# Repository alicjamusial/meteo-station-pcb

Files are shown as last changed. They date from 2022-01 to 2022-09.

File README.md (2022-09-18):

# METEO STATION – PCB based on ESP32 


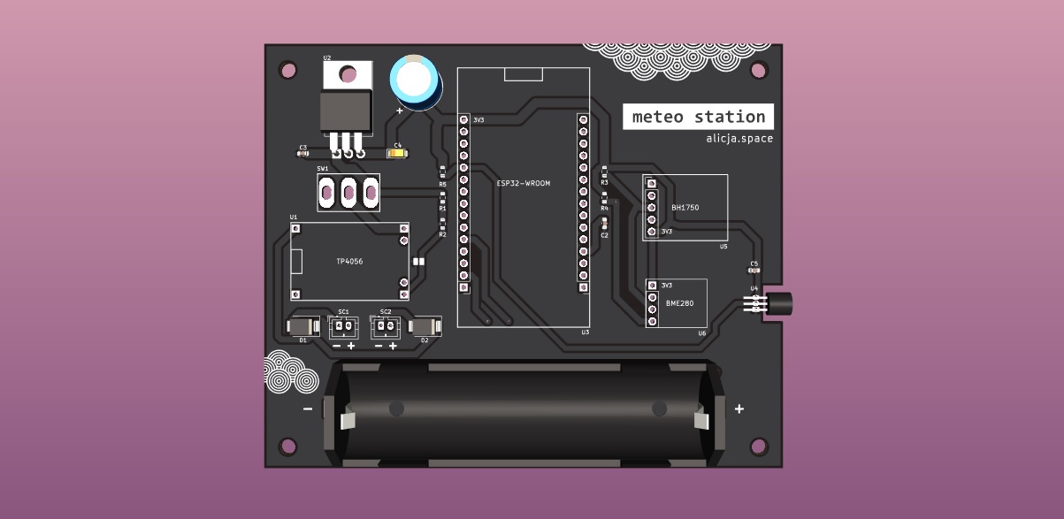
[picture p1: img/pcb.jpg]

<p align="center">
  Light
&nbsp; &nbsp; &nbsp;
  Dark
</p>

### ◾ About the project

**Meteo station** is my small after-hours project that contains of **three** repositories:
- Meteo station PCB based on ESP32 (this repo)
- [Meteo station code](https://github.com/alicjamusial/meteo-station-code)
- [Meteo station 3D prints](https://github.com/alicjamusial/meteo-station-3d-print)

As the name suggest, is a DIY self-sufficient weather measuring device. I decided to design it as a PCB board with goldpins to stick-in or stick-out individual components and sensors (ESP32, BME280 etc.) to make it more reusable. It could have - of course - been integrated on board, but it would be more expensive and time-consuming to create.

As you can see - the project is designed with minimal effort 🙂 But works!

> **Warning** <br>
> This is a hobbyist project. I'm not an electronic engineer so I take no responsibility for any possible issues you may encounter :)

Gerber files for version 1.0 of Meteo Station is available [in the releases section](https://github.com/alicjamusial/meteo-station/releases/tag/release-1.0.0).

The board was designed using [KiCad](https://kicad.org/) (version: `6.0`).

I was inspired by solution created by [this guy on Instructables](https://www.instructables.com/Solar-Powered-WiFi-Weather-Station-V30/). He did a good job, so I strongly recommand exploring his meteo projects!

### ◾ Sensors & components
**Components:**
- ESP32 (ESP-WROOM-32) - main computer (with LEDs, LDO, USB-to-UART unsoldered)
- TP4056 - battery charger
- solar panel - I finally used DFRobot FIT0601 Monocrystalline Solar Panel (5V, 1A)
- 18650 battery + holder
- slide switch, LDO etc. - according to the KiCad project

**Sensors:**
- BME280 - humidity, pressure, temperature
- DS18B20 - temperature
- BH1750 - light (should be mounted on cables - outside of the box)

**Other stuff that you may need:**
- access to 3D printer to print a Stevenson cage and solar panel holder
- server (e.g. RaspberryPi) with Influx database and Grafana instance to gather data from the station and display it in a nice way

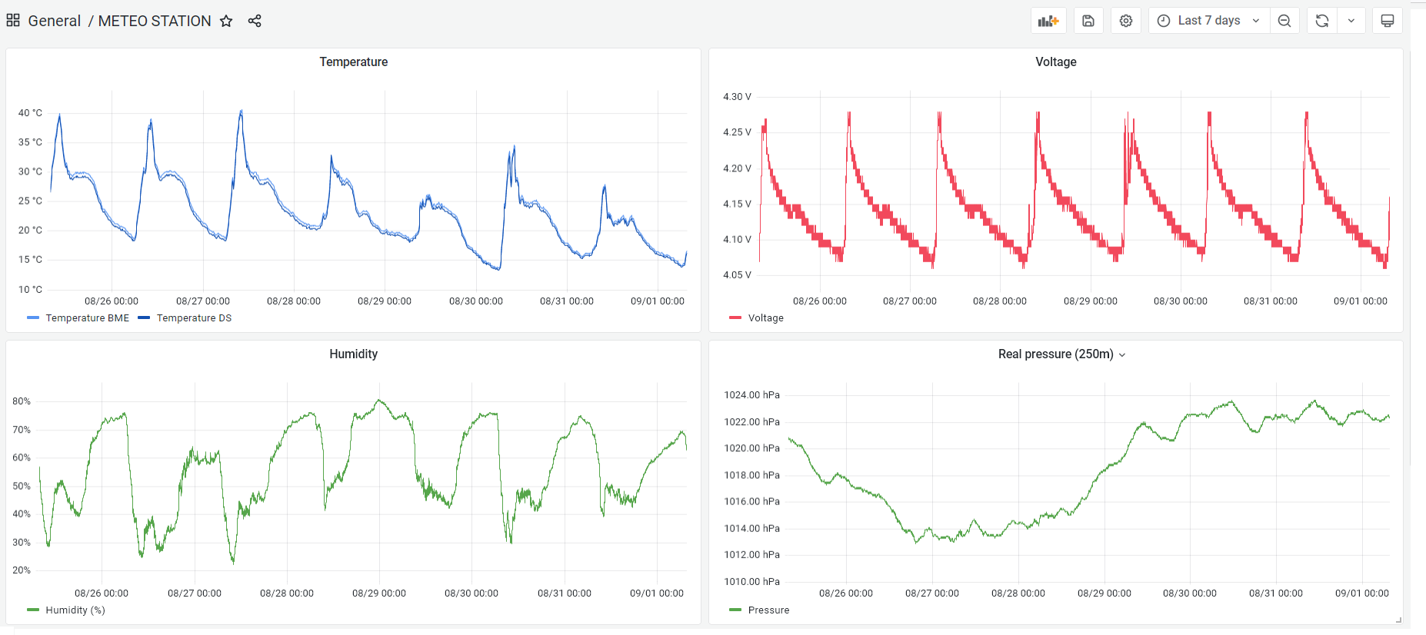
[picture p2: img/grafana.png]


### ◾ Useful tips

- **important!** - it's a good idea to prepare your ESP32 before placing it in the station - I unsoldered all unnecessary components from it to lower the power consumption. You can see more details on [my twitter](https://twitter.com/alicja_musial/status/1494784125051584515),
- there are two possibilites to connect a solar panel to the PCB - via mini USB in the TP charger or using SC1 and SC2 connectors - depending on which solar panel you buy,
- choose the biggest solar panel you can,
- adjust timings in software to avoid complete discharge of the battery.

### ◾ Adjust it to your needs!
This is an absolutely hobbyst project :) You can use it as a reference to create something a lot better.

### ◾ License
Meteo Station PCB is available on Creative Commons Attribution Share Alike 4.0 International license (more in [license file](LICENSE.txt)). You are free to use it, modify it and produce as many of your own boards as you need.

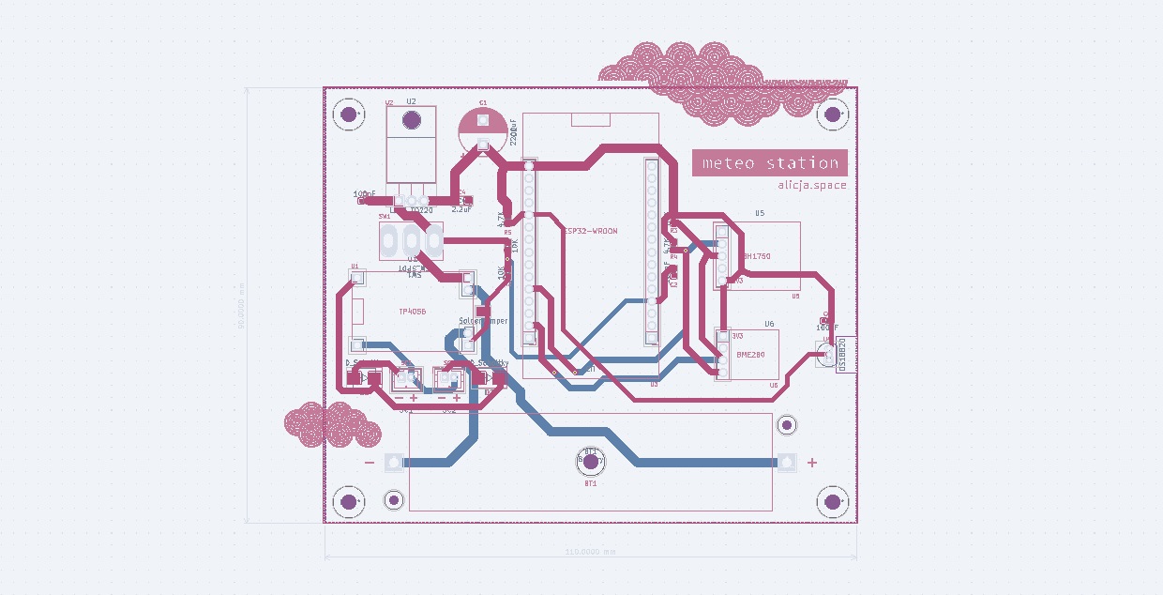
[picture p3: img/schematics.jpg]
schema

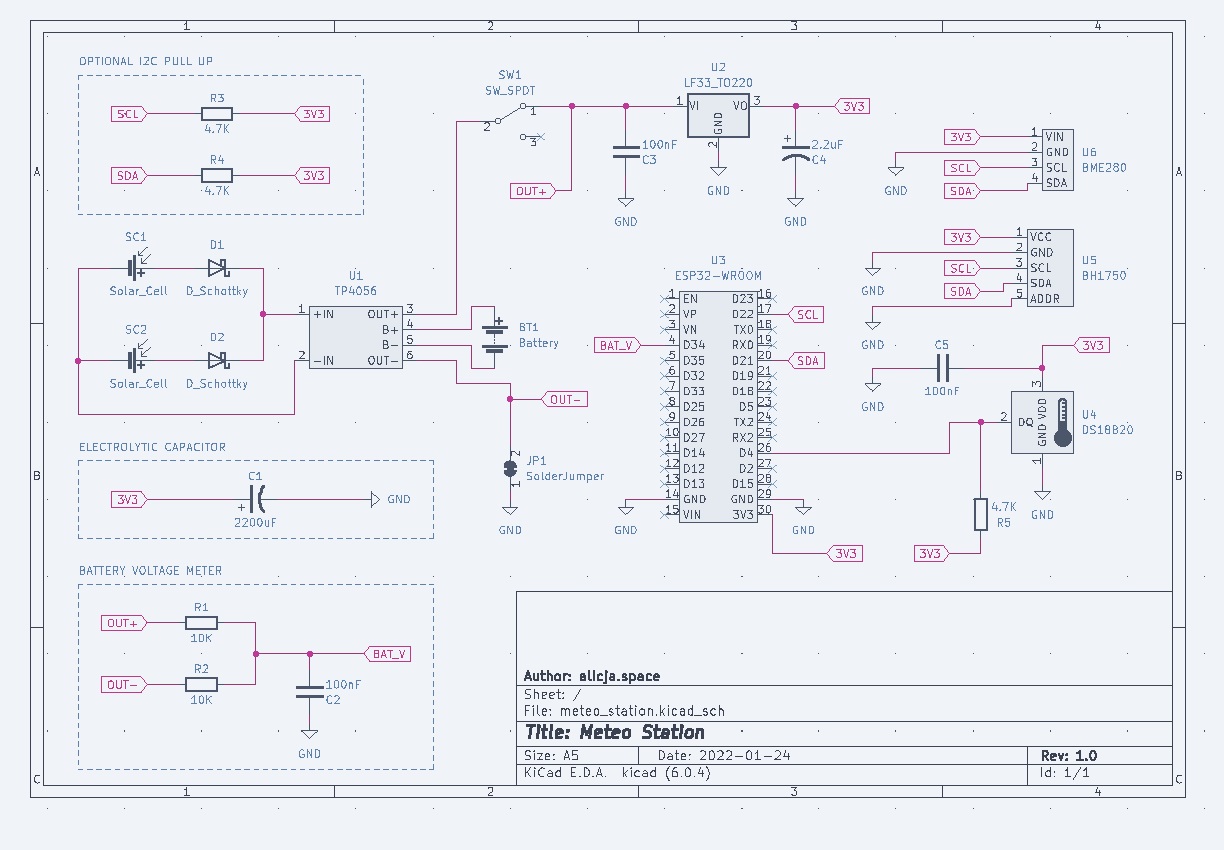
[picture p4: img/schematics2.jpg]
schema


### ◾ Final result

Cable tie and tape for the win ;)

<p align="center">
  Dark
</p>

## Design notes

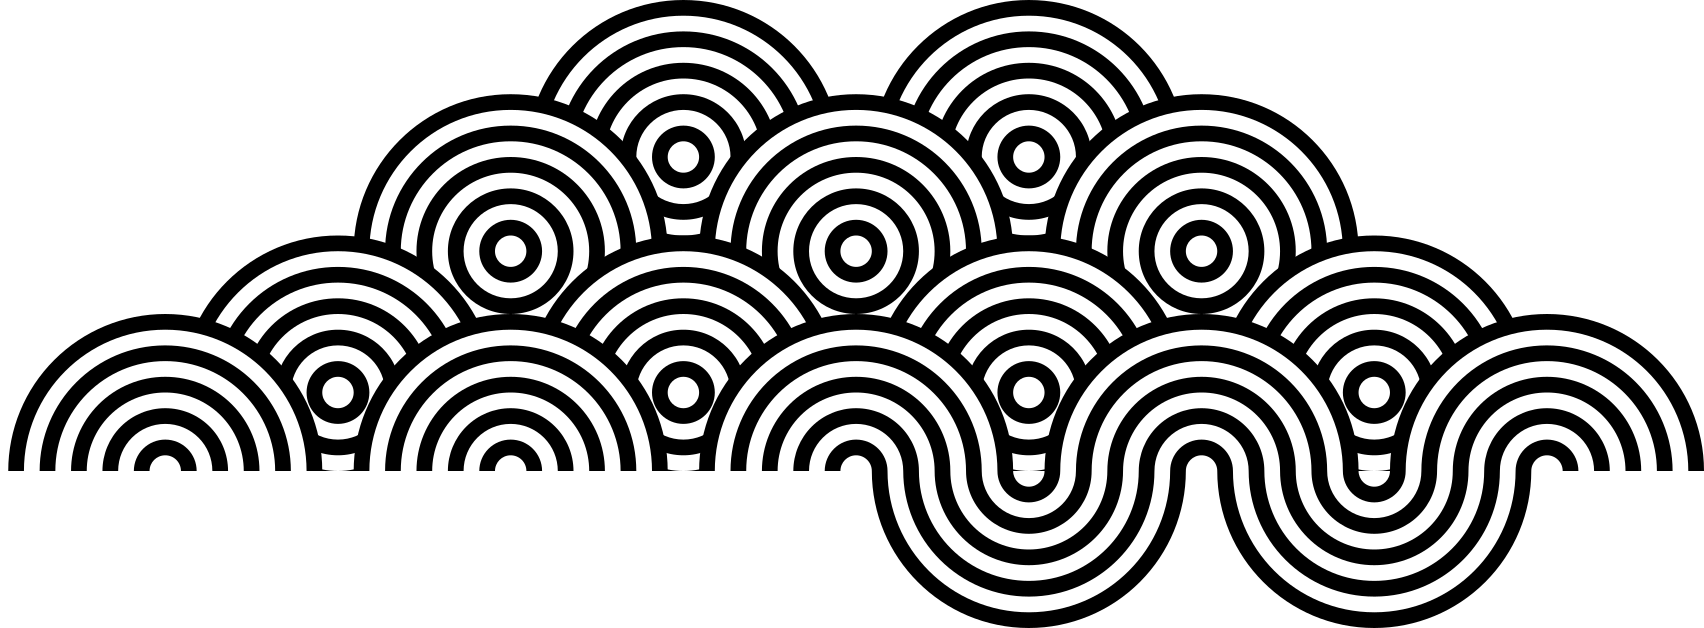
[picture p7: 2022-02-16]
meteo_station/graphics/chmurka3.png

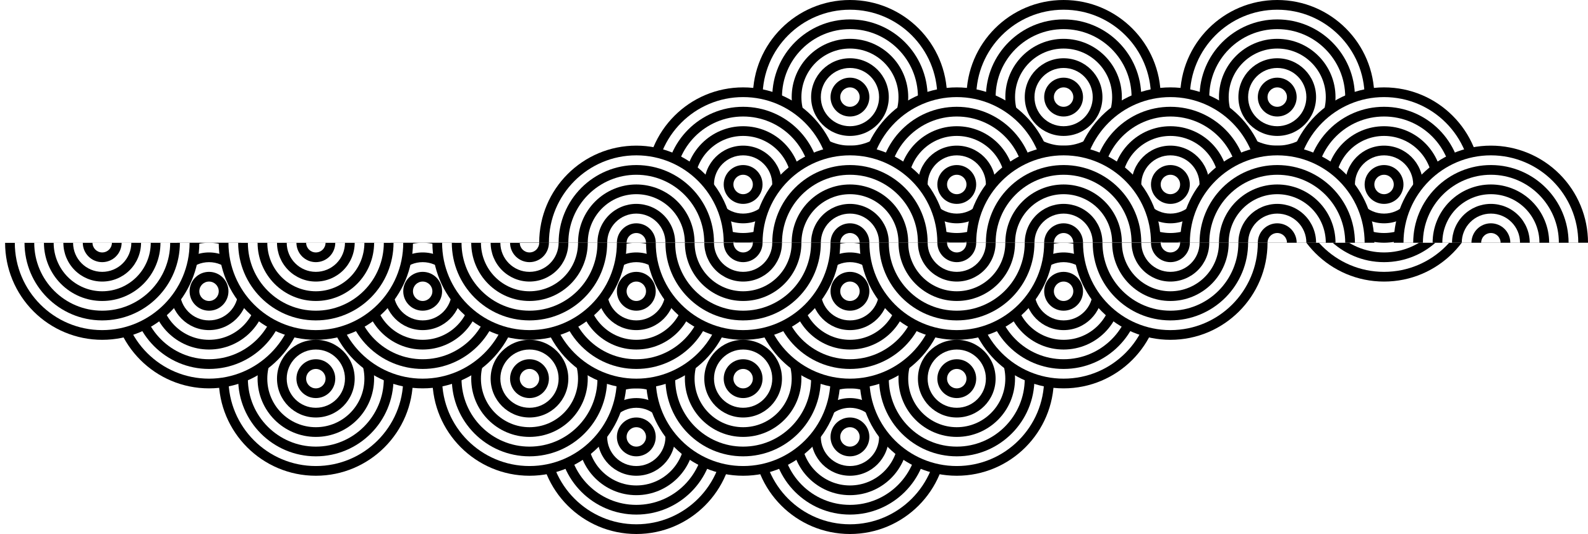
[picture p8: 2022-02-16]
meteo_station/graphics/chmurka_rotated.png

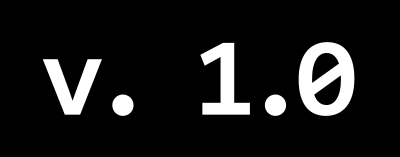
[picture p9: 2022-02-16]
meteo_station/graphics/version2.png

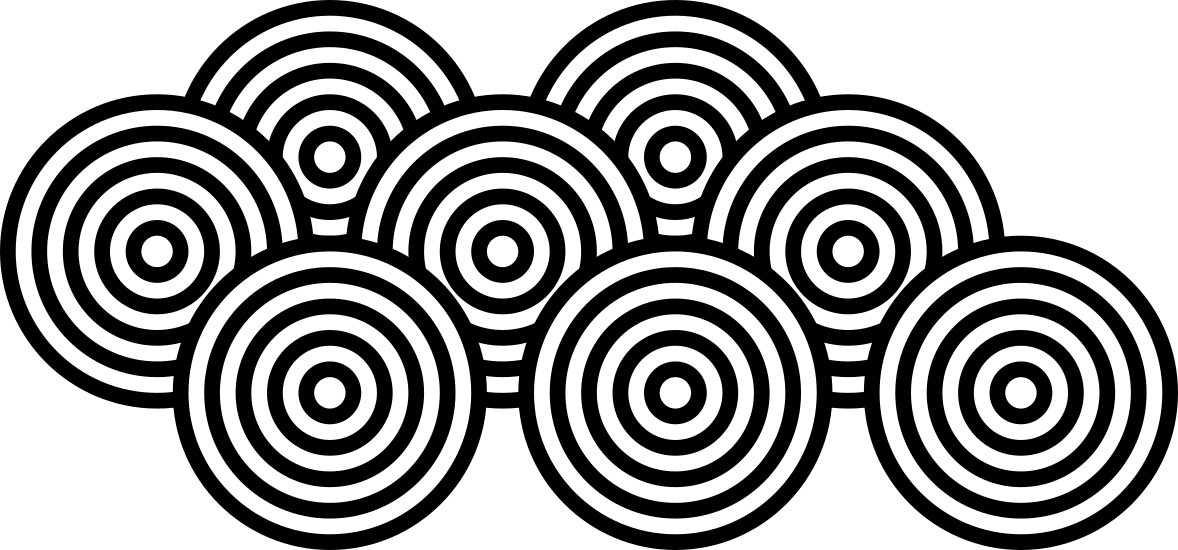
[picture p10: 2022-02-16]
meteo_station/graphics/chmurka2.png

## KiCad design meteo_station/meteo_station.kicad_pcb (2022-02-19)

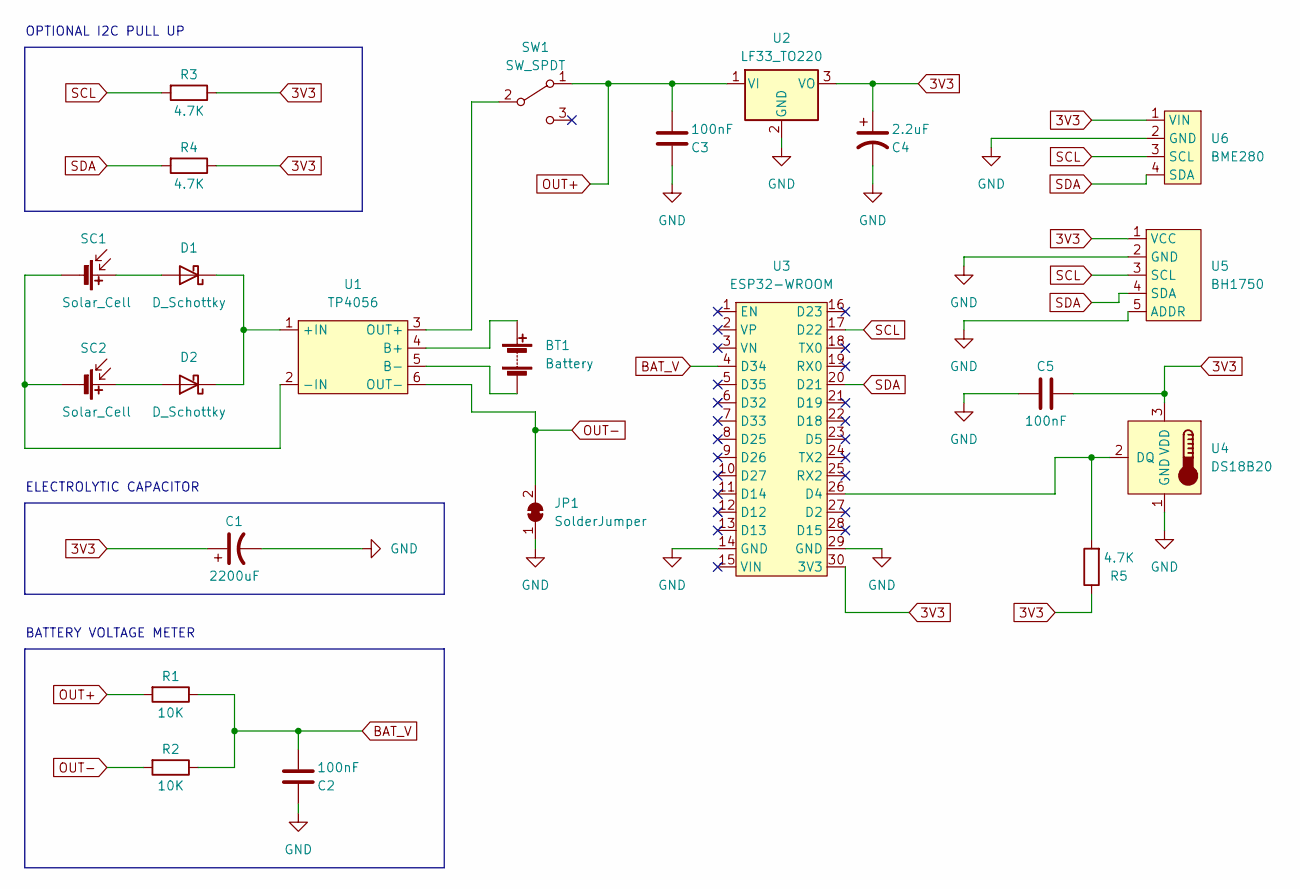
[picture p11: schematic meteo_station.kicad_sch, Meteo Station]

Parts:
BT1: Battery; BatteryHolder
C1: 2200uF; CP_Radial_D10.0mm_P5.00mm
C2, C3, C5: 100nF; C_0603_1608Metric
C4: 2.2uF; CP_EIA-3216-18_Kemet-A
D1, D2: D_Schottky; D_SMB
JP1: SolderJumper; SolderJumper-2_P1.3mm_Bridged_Pad1.0x1.5mm
R1, R2: 10K; R_0603_1608Metric
R3, R4, R5: 4.7K; R_0603_1608Metric
SC1, SC2: Solar_Cell; SolarPanel_JST
SW1: SW_SPDT; MTS102
U1: TP4056
U2: LF33_TO220; TO-220-3_Horizontal_TabDown
U3: ESP32-WROOM
U4: DS18B20; TO-92_Inline
U5: BH1750
U6: BME280

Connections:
3V3: C1.1, C4.1, C5.2, R3.1, R4.1, R5.1, U2.3 (VO), U3.30 (3V3), U4.3 (VDD), U5.1 (VCC), U6.1 (VIN)
BAT_V: C2.1, R1.1, R2.1, U3.4 (D34)
GND: C1.2, C2.2, C3.2, C4.2, C5.1, JP1.1 (A), U2.2 (GND), U3.14 (GND), U3.29 (GND), U4.1 (GND), U5.2 (GND), U5.5 (ADDR), U6.2 (GND)
unnamed: BT1.1 (+), U1.4 (B+)
unnamed: BT1.2 (-), U1.5 (B-)
unnamed: D1.1 (K), D2.1 (K), U1.1 (+IN)
unnamed: D1.2 (A), SC1.1 (+)
unnamed: D2.2 (A), SC2.1 (+)
unnamed: R5.2, U3.26 (D4), U4.2 (DQ)
unnamed: SC1.2 (-), SC2.2 (-), U1.2 (-IN)
unnamed: SW1.2 (B), U1.3 (OUT+)
OUT+: C3.1, R1.2, SW1.1 (A), U2.1 (VI)
OUT-: JP1.2 (B), R2.2, U1.6 (OUT-)
SCL: R3.2, U3.17 (D22), U5.3 (SCL), U6.3 (SCL)
SDA: R4.2, U3.20 (D21), U5.4 (SDA), U6.4 (SDA)

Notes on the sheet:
OPTIONAL I2C PULL UP
ELECTROLYTIC CAPACITOR
BATTERY VOLTAGE METER

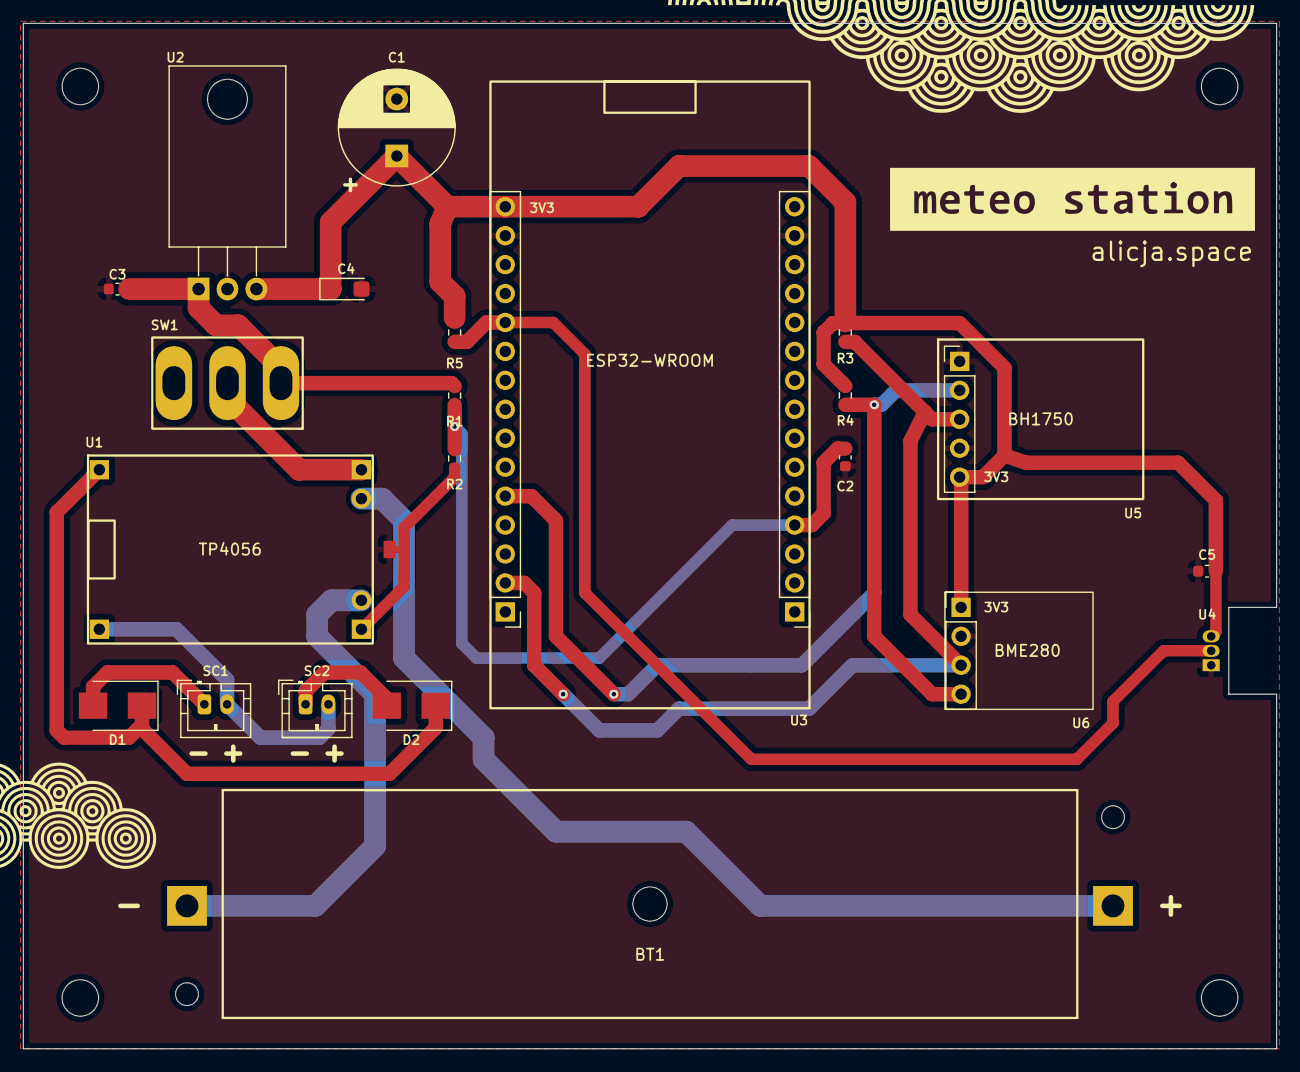
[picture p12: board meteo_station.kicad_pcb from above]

Board: 2 copper layers, 110.0 x 90.0 mm, 23 parts (0 on the bottom side), 15 nets.

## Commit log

2022-01-24 Repo init
    [meteo_station.kicad_pcb, meteo_station.kicad_sch]
2022-01-24 Net fixes
    [meteo_station.kicad_sch]
2022-01-24 First random assignment
    [meteo_station.kicad_pcb, meteo_station.kicad_sch]
2022-01-24 First draft of PCB
    [meteo_station.kicad_pcb, meteo_station.kicad_sch]
2022-01-25 Add some footprints
    [meteo_station.kicad_pcb, meteo_station.kicad_sch]
2022-01-25 Preliminary design
    [meteo_station.kicad_pcb]
2022-01-25 Add some routes
    [meteo_station.kicad_pcb]
2022-01-25 Add LDO and battery voltage meter
    [meteo_station.kicad_sch]
2022-01-29 Fix some footprints
    [meteo_station.kicad_sch]
2022-01-29 Add second solar panel
    [meteo_station.kicad_sch]
2022-01-29 Update termometer footprint
    [meteo_station.kicad_sch]
2022-01-29 PCB adjustments
    [meteo_station.kicad_pcb]
2022-01-29 PCB v2
    [meteo_station.kicad_pcb, meteo_station.kicad_sch]
2022-02-13 Change rotation to make USBs visible
    [meteo_station.kicad_pcb]
2022-02-13 Add some routing
    [meteo_station.kicad_pcb]
2022-02-13 Start working on logo
    [meteo_station.kicad_pcb, meteo_station.kicad_sch]
2022-02-16 Add jumper & version
    [meteo_station.kicad_pcb, meteo_station.kicad_sch]
2022-02-16 Add images
    [meteo_station.kicad_pcb]
2022-02-19 Add supercapacitor and 100nF
    [meteo_station.kicad_sch]
2022-02-19 Finished moving
    [meteo_station.kicad_pcb]
2022-02-19 new tracks
    [meteo_station.kicad_pcb]
2022-02-19 Very thick routes
    [meteo_station.kicad_pcb]
2022-02-19 Typo & label
    [meteo_station.kicad_pcb, meteo_station.kicad_sch]
